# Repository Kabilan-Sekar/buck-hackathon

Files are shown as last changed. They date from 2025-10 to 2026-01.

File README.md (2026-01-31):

# buck-hackathon
# Buck Converter Design Project

This repository contains the design files, simulation results, and PCB layout for a **Buck Converter** (step-down DC-DC power converter).

---

## Repository Structure

| Folder | Contents | Key Files Included |
| :--- | :--- | :--- |
| `design/` | Simulation models and control loop analysis. | `finalbuck.slk`, `bode_plot.png`, `waveforms.png` |
| `pcb/` | Printed Circuit Board (PCB) fabrication and assembly files. | `layout.kicad_pcb`, `schematic.kicad_sch`, `bom.xlsx` |
| (root) | General project documentation and high-level files. | `bonus_task.pdf`, `control_diagram.pdf` |

---

## Design and Analysis Files (`design/` folder)

* **`finalbuck.slk`**: The main **Simulink Model** used for the transient and steady-state simulation of the converter.
* **`bode_plot.png`**: Image showing the **Bode Plot** of the control loop, critical for verifying stability (phase and gain margins).
* **`waveforms.png`**: Image of key **time-domain waveforms** from the simulation (e.g., output voltage ripple, inductor current).
* **`notes.txt`**: General observations and design notes.

---

## PCB Files (`pcb/` folder)

The PCB was designed using **KiCad Board 9.0**.

* **`schematic.kicad_sch`**: The complete circuit diagram and component definitions.
* **`layout.kicad_pcb`**: The physical board layout and routing.
* **`bom.xlsx`**: The **Bill of Materials (BOM)** listing all required components for assembly.

---

## Documentation (Root directory)

* **`control_diagram.pdf`**: PDF detailing the **control strategy** and block diagram used for the feedback system.
* **`bonus_task.pdf`**: Document related to an extended design specification or analysis task.

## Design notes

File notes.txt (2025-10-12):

ZEROWINGS AEROSPACE TEAM 319579
ASYNCHRONOUS BUCK CONVERTER DESIGN AND ANALYSIS USING CURRENT-MODE CONTROL
1. Introduction
This project focuses on the design, simulation, and analysis of a digitally controlled buck converter implemented in MATLAB Simulink. The objective is to achieve regulated 12 V output from a 24 V input supply using current-mode control and to evaluate performance under both steady-state and transient conditions. The project also includes component selection, PCB design, load transient and small signal simulation in KICAD AND MATLAB SIMULINK respectively
________________________________________
2. Design Specifications
Parameter	Value
Input Voltage	24 V
Output Voltage	12 V
Switching Frequency	200 kHz
Load Resistance	10 Ω nominal (variable for transient test)
Inductance	400 µH
Capacitance	100 µF
The converter is designed to operate in continuous conduction mode with a nominal duty ratio of 0.5. The chosen component values provide low output voltage ripple, stable transient response, and maintain efficiency above 90 percent under rated load conditions.
________________________________________
3. Step 1 — Design and Simulation (MATLAB Simulink)
3.1 Simulation Model Overview
The system is modeled in MATLAB Simulink, consisting of the following main subsystems:
•	Power Stage:
Includes a MOSFET as the main switch, a Schottky diode as the freewheeling path, a 400 µH output inductor, and a 100 µF output capacitor.
•	Control Stage:
Implements current-mode control with an inner current loop and outer voltage loop. A current sensing block measures the inductor current and compares it with the reference derived from the voltage error amplifier. For comparison, a digital PID controller is also implemented by discretizing the converter model using a sampling period of 5 microseconds.
•	Load Transient Simulation:
A signal-controlled variable resistor is used to emulate load transients. The load resistance is made sinusoidal to evaluate transient recovery and control loop stability.
Screenshot 1: Simulink model overview showing current-mode controlled buck converter.
Screenshot 2: Transient response using variable load resistor.
________________________________________
3.2 Steady-State and Dynamic Results
•	Output voltage: 12 V regulated at nominal load
•	Inductor current ripple: Approximately 3 of average load current
•	Output voltage ripple: Less than 50 mV peak-to-peak
•	Transient response: Settling time below 1.5 ms for 50% load step
•	Efficiency: Above 90% at full load with minimal switching losses
The transient performance confirms that the converter maintains stability and quick recovery under dynamic load variations. The steady-state response shows negligible deviation in output voltage, indicating good control design.
________________________________________
3.3 Small-Signal and Frequency Response
The converter is linearized around the steady-state operating point using MATLAB’s control design tools. The resulting Bode plot confirms adequate stability margins:
•	Phase Margin: Approximately 50 degrees
•	Gain Margin: Above 10 dB
These results validate the effectiveness of the compensator design and ensure robust control under parameter variations.
Screenshot 3: Small-signal frequency response showing magnitude and phase plot.
________________________________________
4. Step 2 — Component Selection and PCB Design
4.1 Component Selection
Component	Specification	Selection Justification
MOSFET	40 V, 30 A, low RDS(on)	Ensures low conduction losses and fast switching
Diode	Schottky 40 V, 10 A	Low forward voltage and minimal reverse recovery losses
Inductor	400 µH, 3 A rated	Chosen to maintain continuous conduction and minimize ripple
Capacitor	100 µF, low ESR	Reduces voltage ripple and enhances transient response
Controller	Custom digital PID (Simulink)	Provides flexible gain tuning and noise immunity
4.2 PCB Design and Layout
The PCB schematic and layout were developed in Kicad. Key layout considerations include:
1.	Minimized High-Current Loop Area (Switching Loop)
2.	Short and Wide Input/Output Power Paths
3.	Strategic Placement of Input Capacitors
4.	Effective Thermal Dissipation
5.	Output Inductor and Output Capacitor Separation from Switching Nodes
6.	"Quiet" vs. "Noisy" Ground Separation
7.	Sensing/Feedback Trace Routing
8.	Vias Used for Thermal Relief and Current Carrying
9.	Clear Delimitation of Power and Signal Areas
10.	Use of a Ground Plane
Deliverables:
•	Bill of Materials (BOM)
•	PCB layout and schematic files
•	3D render of final PCB
•	Frequency response plot from small-signal analysis
________________________________________
5. Step 3 — Thermal Simulation
A preliminary thermal analysis was performed using SolidWorks Simulation. The PCB model was imported with realistic component power losses based on switching and conduction characteristics.
•	Ambient temperature: 25°C
•	Steady-state thermal analysis: Conducted under full-load operation
•	Hotspot temperature: Identified near the MOSFET and diode regions
•	Recommendations: Increase copper area under switching components, add thermal vias, and use thicker PCB copper layers for improved heat dissipation.
Screenshot 4: Thermal contour plot showing temperature distribution across the PCB.
________________________________________
6. Step 4 — Digital PID Control Implementation
A digital PID controller was implemented to compare with the analog current-mode loop. The gains were tuned to achieve a critically damped response while minimizing steady-state error.
Control Mode	Overshoot	Settling Time	Steady-State Error	Stability
Current-Mode	Low	Fast	Negligible	Excellent
Digital PID	Moderate	Slightly slower	Zero	Stable
Both methods achieved stable regulation, with current-mode control offering faster dynamic response, while the digital PID provided flexibility and easier parameter adjustment in the discrete domain.
________________________________________
7. Step 5 — Efficiency Optimization
Efficiency was evaluated considering conduction, switching, and control losses. The optimized design achieved over 90% efficiency under nominal load due to:

Loss Component	Equation / Estimate	Notes
MOSFET Conduction	Iout² × RDS(on) × D	Low RDS(on) MOSFET; duty cycle 0.5
Diode Conduction	Iout × Vf × (1-D)	Schottky diode forward drop 0.5 V
MOSFET Switching	0.5 × Vin × Iout × (tr + tf) × fs	Rise/fall time 50 ns, fs = 200 kHz
Inductor Copper Loss	Iout² × Rseries	3 Ω equivalent series resistance
Inductor Core Loss	Estimated	Typical low-frequency core loss
Capacitor ESR Loss	Iout² × ESR	ESR ≈ 0.01 Ω
________________________________________
8. Project Checklist
Task	Status
Verified converter simulation (step response, steady-state)	Completed
Stable closed-loop operation	Achieved
PCB schematic and layout	Completed
Frequency response analysis	Completed
Thermal analysis	TBD
Final report and presentation	Ready
________________________________________
9. Conclusion
A buck converter operating at 200 kHz with 24 V input and 12 V regulated output has been successfully designed and simulated. The converter demonstrates stable closed-loop behavior under both steady and transient conditions. The comparison between current-mode and digital PID control highlights the trade-off between response speed and design flexibility.
The PCB design and thermal evaluation further validate the converter’s practical feasibility, achieving over 90 percent efficiency. Future work includes complete thermal optimization and hardware prototyping.

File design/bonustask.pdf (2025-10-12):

⚙ 1. SYSTEM OVERVIEW
A current-mode controlled buck converter has two feedback loops:
(a) Outer loop → Voltage control
- Maintains the desired output voltage.
- Generates a reference current ( i

ref ).
(b) Inner loop → Current control
- Forces the inductor current ( iL

) to follow ( i

ref ) on every switching cycle.

🧩 2. POWER STAGE MODEL
Let’s start from the averaged buck converter equations (continuous conduction mode, CCM):

Where:
- ( D ) = duty ratio
- ( iL

) = inductor current
- ( Vo

) = output voltage

⚡ 3. LINEARIZATION (SMALL-SIGNAL MODEL) We write each variable as:

where ( X ) is steady-state value, (x ) is a small perturbation. So:

🔹 4. VOLTAGE-MODE CONTROL TRANSFER FUNCTION (for reference)
In voltage-mode control, the control variable is ( d ) directly, so the small-signal control-to-output transfer is:

This is second-order double pole at ( ω0 = 1/ LC ).

🔹 5. CURRENT-MODE CONTROL INNER LOOP BEHAVIOR In CMC, duty cycle is not controlled directly by voltage error. Instead:
1. The outer voltage loop outputs a current command ( i

ref ).
2. The inner loop ensures ( iL

) follows ( i

ref ) every cycle.
So, we can write the inner current loop dynamics:
- ( Kc ) = DC gain of current loop (≈ 1 if loop is tight)
- ( p ω ) = crossover of current loop (usually near half switching frequency)
- For frequencies below the switching frequency, ( iL ≈ i

ref ).
Hence, inductor current dynamics are suppressed and the inductor behaves almost instantaneously controlled.

🧮 6. EFFECTIVE SMALL-SIGNAL MODEL We can substitute ( iL ≈ i

ref ) into the capacitor equation:

Taking Laplace transform:

So the control-to-output transfer function becomes:

✅ This is a first-order system!

🔹 7. COMBINED TRANSFER FUNCTION Now combine both loops:
- Outer voltage loop controls ( i

ref ) based on voltage error.
- Inner loop ensures ( iL = i

ref ).
- The plant (power stage) seen by the voltage loop is first-order instead of second-order**. Thus:

and since ( i

ref ) is generated by voltage error amplifier: [

Therefore, the overall closed-loop transfer function is:

🧠 8. INTERPRETATION

Concept | Voltage-Mode | Current-Mode
Effective plant order | 2nd order (LC double pole) | 1st order (C only)
Dominant pole | LC double pole | Output capacitor pole only
Needed compensator | Type III (for 180° phase lag) | Type II (for 90° lag only)
Phase margin | Harder to stabilize | Easier (simpler compensation)
Inner dynamics | Inductor current uncontrolled | Inductor current directly controlled

So, current-mode control linearizes the inductor, making it appear as a current source to the outer loop.

🧮 9. INCLUDING EFFECT OF CURRENT LOOP GAIN In a more realistic model, the inner loop is not perfectly ideal.
Let the inner loop have gain ( Hi(s) = | ).

Ki
1+s/ωπ
Then:
If ( Hi(s) → ∞ ), the ( LC(1 - Hi S | ) ) term cancels the inductor pole — leaving a first-order system.

2

📈 10. FREQUENCY RESPONSE COMPARISON

Property | Voltage-Mode | Current-Mode
DC gain | Vin | R
Number of poles | 2 | 1
ESR zero | Adds phase boost | Still adds boost if ESR present
Phase margin (uncompensated) | ~ 0°–90° | ~ 90°–135°
Bode shape | Resonant dip around ( fLC ) | Smooth roll-off

🧩 11. PHYSICAL INTERPRETATION
- The inner current loop makes the inductor look like a resistor instead of a reactive element.
- From the outer loop’s view:

Vo = Iref. Req

where ( Req ≈ RLoad

|| 1/(sC) )
- Hence, voltage control becomes as simple as controlling the current through an RC network.

🔬 12. PRACTICAL INSIGHT

Scenario | Behavior
Line transient (Vin step) | Inner loop reacts almost instantly — fast correction
Load transient | Outer voltage loop detects Vout deviation, adjusts Iref; inner loop enforces new current quickly
Stability tuning t | Easier — Type II compensator sufficien
Subharmonic oscillation | May appear for duty > 0.5 → requires slope compensation

⚙ 13. FINAL SUMMARY

Parameter | Voltage-Mode Control | Current-Mode Control
Effective order | 2nd (LC) | 1st (C only)

Transfer function

Inner variable | Duty ratio | Inductor current
Outer variable | Output voltage | Output voltage
Compensation | Type III | Type II
Line/load response | Slower | Faster
Stability | Needs ramp comp. only if D > 0.5 | Needs slope comp. (for inner loop)

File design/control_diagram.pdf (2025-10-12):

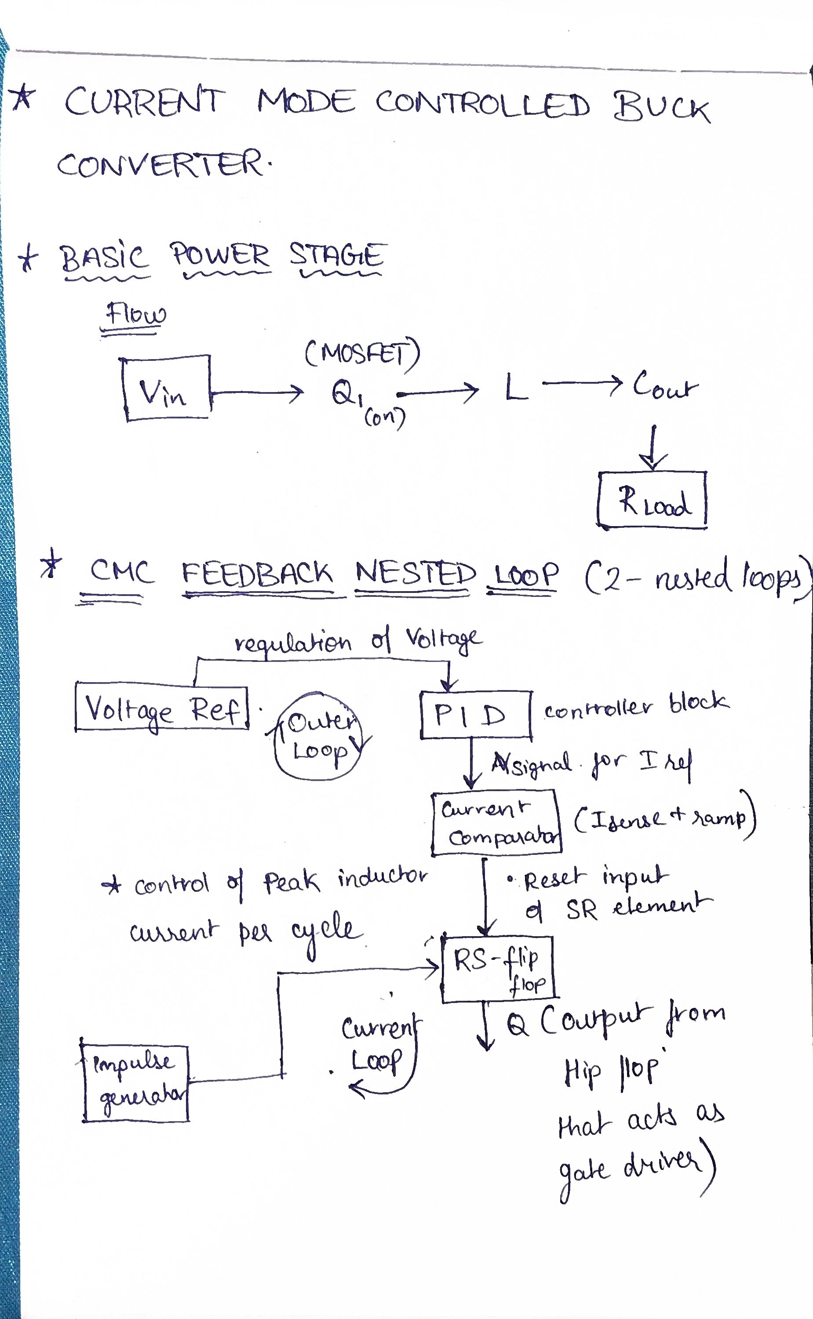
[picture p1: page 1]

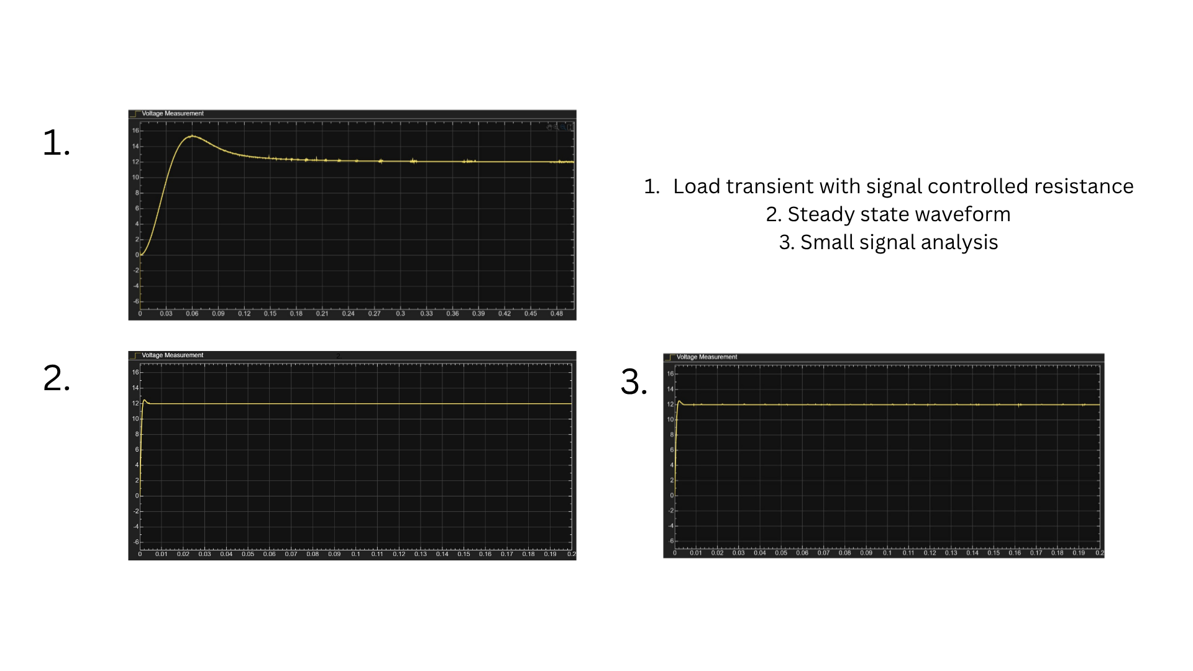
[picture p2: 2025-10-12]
design/waveforms.png

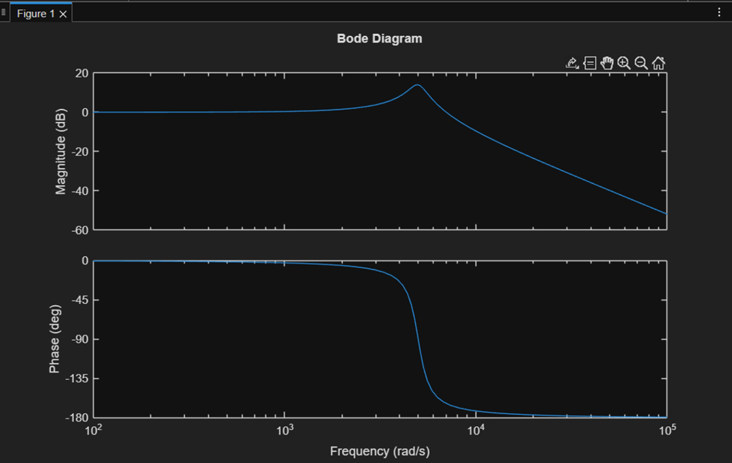
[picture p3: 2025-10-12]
pcb/bode_plot.png

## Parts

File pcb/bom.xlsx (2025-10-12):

Reference | Qty | Value | DNP | Exclude from BOM | Exclude from Board | Footprint | Datasheet
A1 | 1 | Arduino_UNO_R3 |  |  |  | Module:Arduino_UNO_R3 | https://www.arduino.cc/en/Main/arduinoBoardUno
C1 | 1 | C_Polarized |  |  |  | Capacitor_THT:CP_Axial_L10.0mm_D4.5mm_P15.00mm_Horizontal | ~
C2,C3 | 2 | 1μF |  |  |  | Capacitor_THT:C_Axial_L3.8mm_D2.6mm_P12.50mm_Horizontal | ~
D1 | 1 | D_Schottky |  |  |  | Diode_THT:D_DO-41_SOD81_P7.62mm_Horizontal | ~
J1,J2 | 2 | Conn_01x02_Socket |  |  |  | Connector_PinSocket_2.54mm:PinSocket_1x02_P2.54mm_Horizontal | ~
L1 | 1 | 400μH |  |  |  | Inductor_THT:L_Axial_L6.6mm_D2.7mm_P2.54mm_Vertical_Vishay_IM-2 | ~
MES2 | 1 | Voltmeter_AC |  |  |  | TerminalBlock_4Ucon:TerminalBlock_4Ucon_1x02_P3.50mm_Horizontal | ~
Q3 | 1 | IRLIZ44N |  |  |  | Package_TO_SOT_THT:TO-220F-3_Vertical | http://www.irf.com/product-info/datasheets/data/irliz44n.pdf
R1 | 1 | 3.791409Ω |  |  |  | Resistor_THT:R_Axial_DIN0617_L17.0mm_D6.0mm_P20.32mm_Horizontal | ~
R2 | 1 | 13.319585Ω |  |  |  | Resistor_THT:R_Axial_DIN0309_L9.0mm_D3.2mm_P25.40mm_Horizontal | ~
U1 | 1 | LM555xM |  |  |  | Package_SO:SOIC-8_3.9x4.9mm_P1.27mm | http://www.ti.com/lit/ds/symlink/lm555.pdf

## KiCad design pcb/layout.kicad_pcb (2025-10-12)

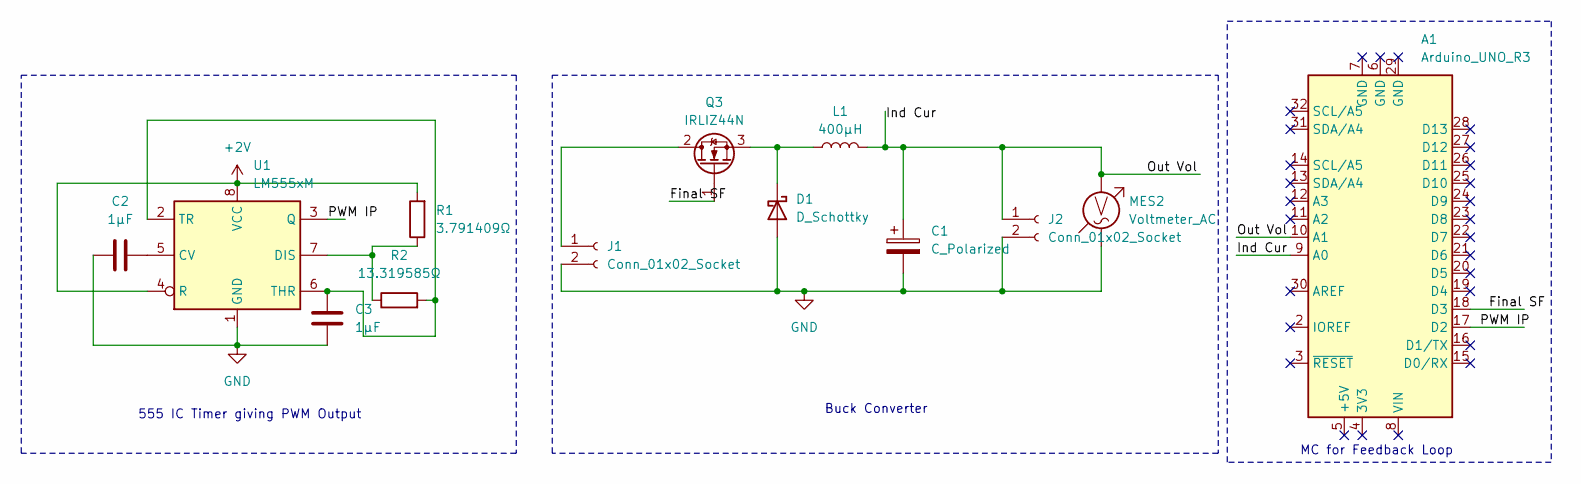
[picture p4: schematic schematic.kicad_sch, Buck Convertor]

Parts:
A1: Arduino_UNO_R3
C1: C_Polarized; CP_Axial_L10.0mm_D4.5mm_P15.00mm_Horizontal
C2, C3: 1μF; C_Axial_L3.8mm_D2.6mm_P12.50mm_Horizontal
D1: D_Schottky; D_DO-41_SOD81_P7.62mm_Horizontal
J1, J2: Conn_01x02_Socket; PinSocket_1x02_P2.54mm_Horizontal
L1: 400μH; L_Axial_L6.6mm_D2.7mm_P2.54mm_Vertical_Vishay_IM-2
MES2: Voltmeter_AC; TerminalBlock_4Ucon_1x02_P3.50mm_Horizontal
Q3: IRLIZ44N; TO-220F-3_Vertical
R1: 3.791409Ω; R_Axial_DIN0617_L17.0mm_D6.0mm_P20.32mm_Horizontal
R2: 13.319585Ω; R_Axial_DIN0309_L9.0mm_D3.2mm_P25.40mm_Horizontal
U1: LM555xM; SOIC-8_3.9x4.9mm_P1.27mm

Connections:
+2V: R1.2, U1.4 (R), U1.8 (VCC)
/Final SF: A1.18 (D3), Q3.1 (G)
/Ind Cur: A1.9 (A0), A1.10 (A1), C1.1, J2.1, L1.2, MES2.2
/PWM IP: A1.17 (D2), U1.3 (Q)
GND: C1.2, C2.1, C3.2, D1.2 (A), J1.2, J2.2, MES2.1, U1.1 (GND)
unnamed: D1.1 (K), L1.1, Q3.3 (S)
unnamed: J1.1, Q3.2 (D)
unnamed: C2.2, U1.5 (CV)
unnamed: R1.1, R2.1, U1.7 (DIS)
unnamed: C3.1, R2.2, U1.2 (TR), U1.6 (THR)

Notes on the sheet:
555 IC Timer giving PWM Output
MC for Feedback Loop
Buck Converter

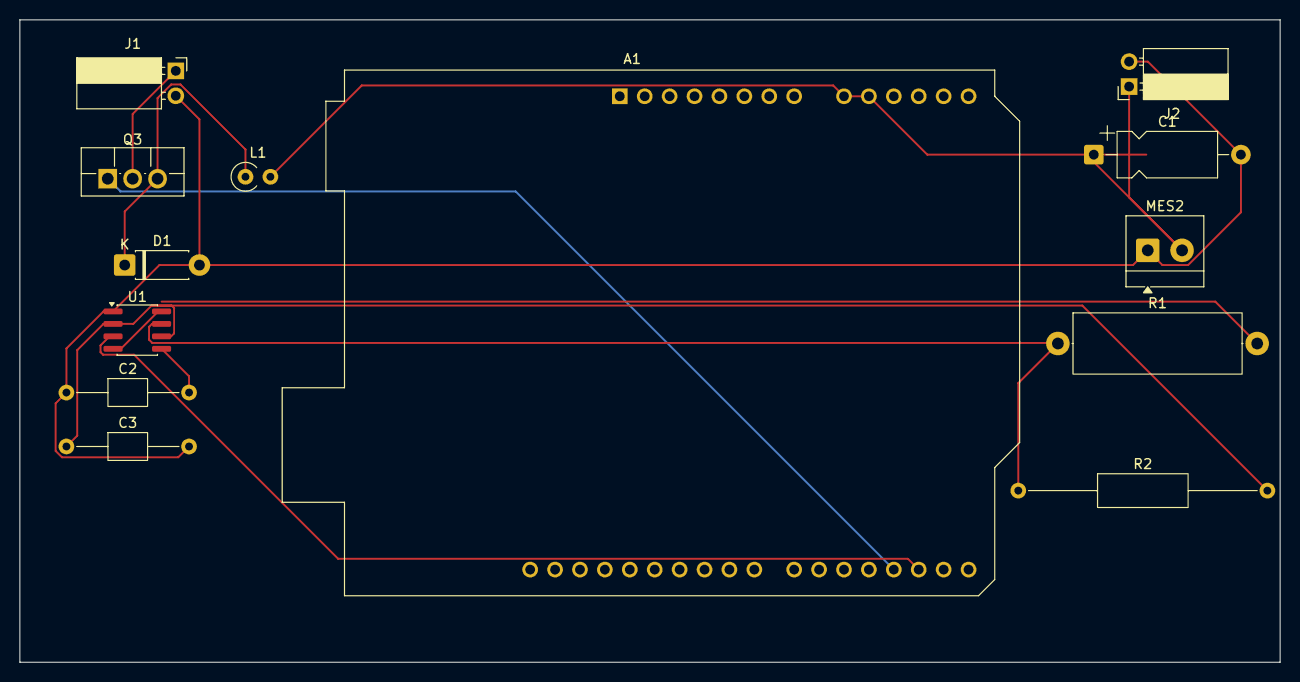
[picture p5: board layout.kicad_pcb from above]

Board: 2 copper layers, 128.5 x 65.5 mm, 13 parts (0 on the bottom side), 10 nets.
